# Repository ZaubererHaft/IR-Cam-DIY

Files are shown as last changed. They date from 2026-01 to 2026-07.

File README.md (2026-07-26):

# DIY IR Camera based on the MLX90640 IR sensor array

## Hardware

### Schematic

### Layout

### Chassis

## Software

### Display

### USB

### Sensor

### Flash

## ToDos
* Implement Config file [x]
* Fix saved image [x]
* Activate upscaling when saving image
* Implement battery level with ADC3 [x]
* Implement auto range or definable range
* Fix warnings in user_interface.c
* Replace Error_Handler with a suited dialogue

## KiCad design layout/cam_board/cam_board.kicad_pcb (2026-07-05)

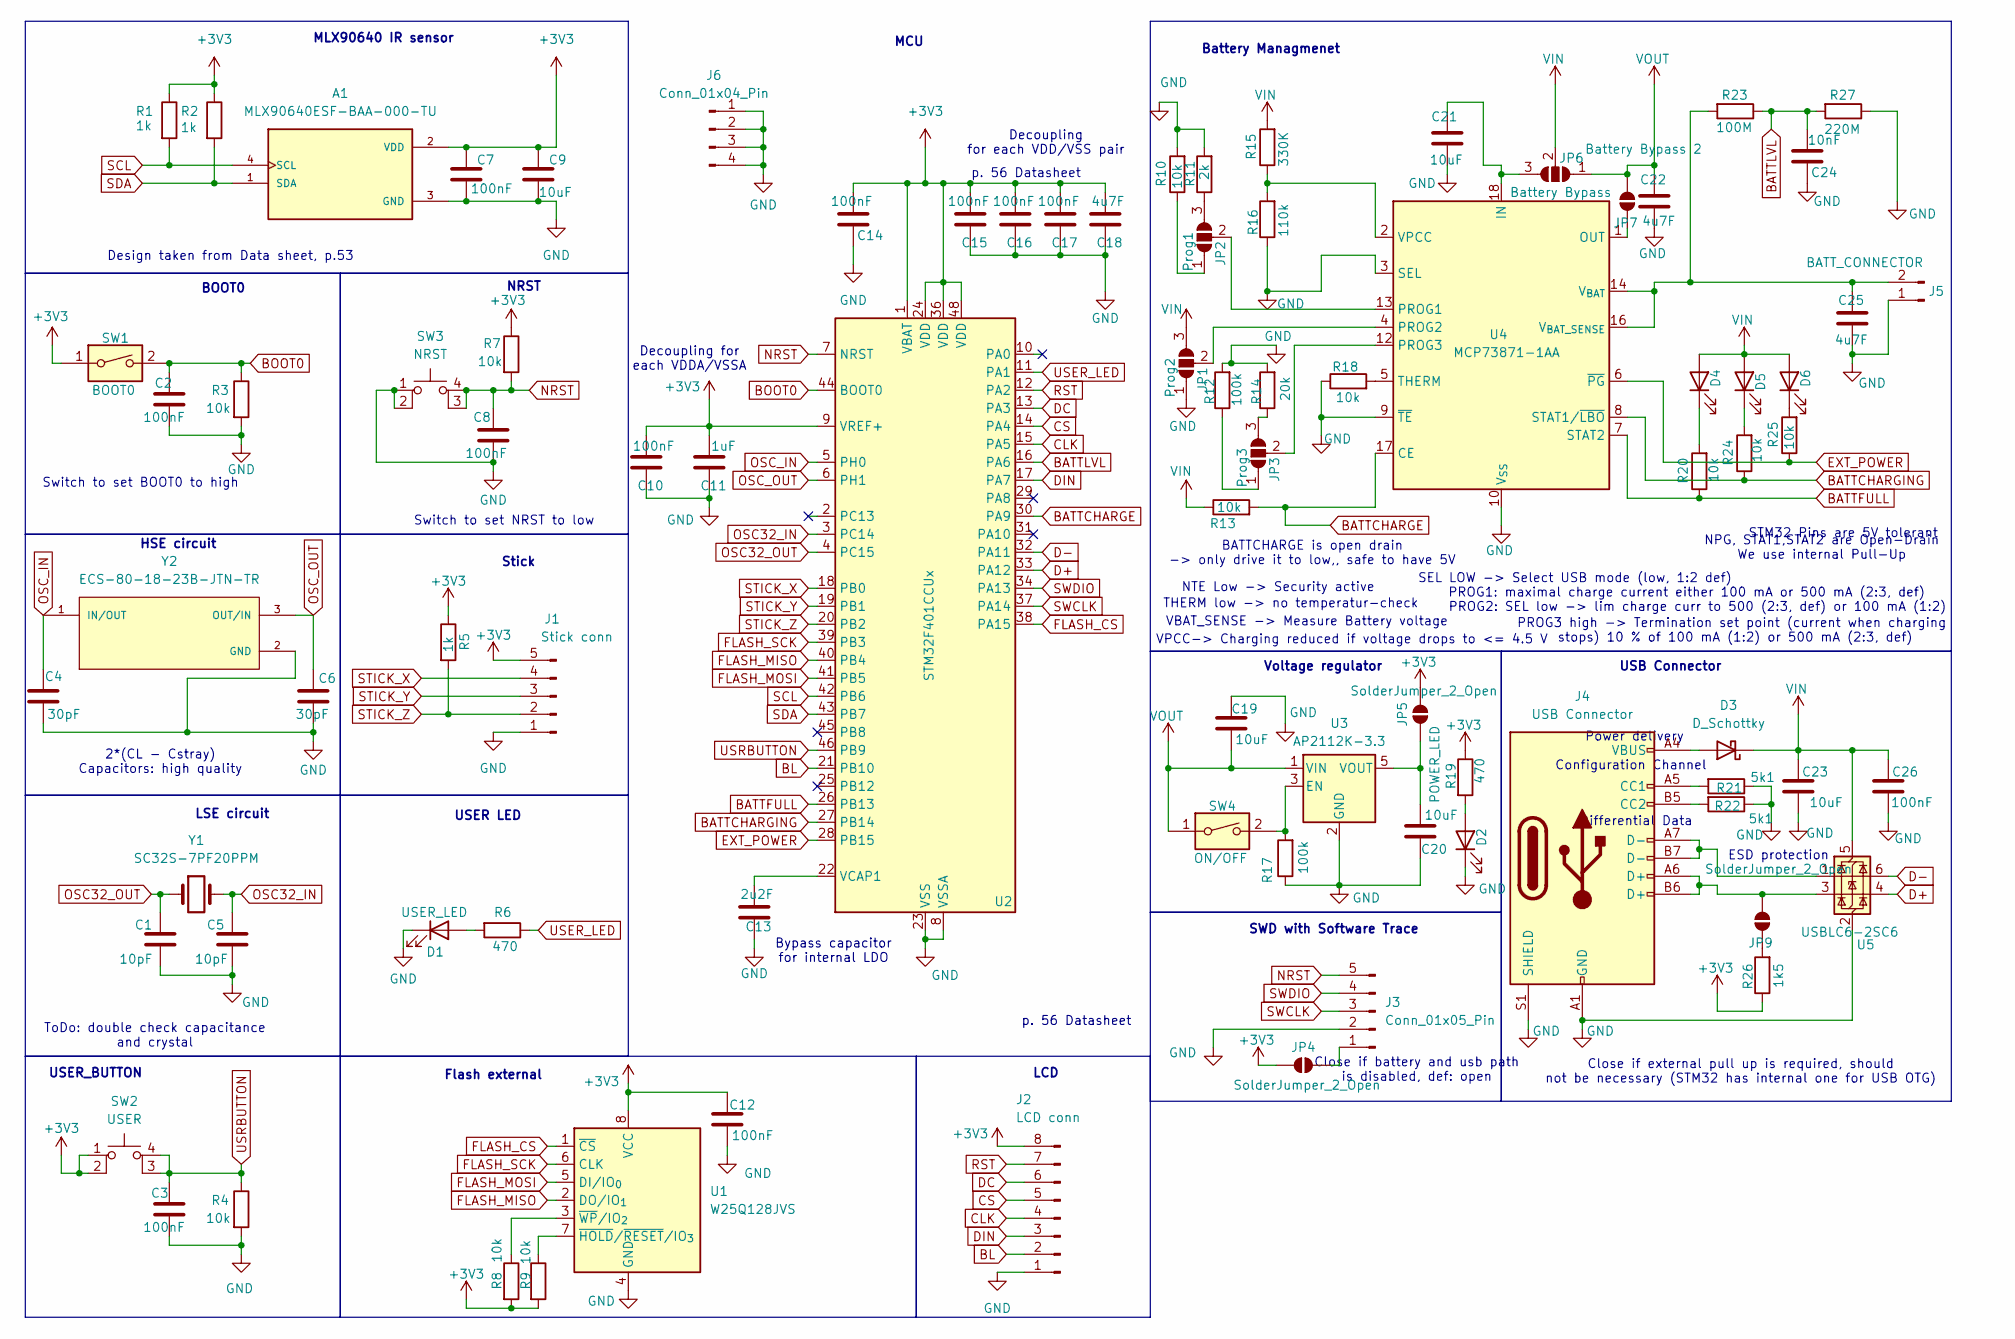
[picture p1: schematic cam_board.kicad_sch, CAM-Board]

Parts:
A1: MLX90640ESF-BAA-000-TU; TO292P930H600-4-MLX; PARTREV 11
C1, C5: 10pF; C_0603_1608Metric_Pad1.08x0.95mm_HandSolder
C2, C3, C7, C8, C10, C12, C14, C15, C16, C17, C26: 100nF; C_0603_1608Metric_Pad1.08x0.95mm_HandSolder
C4, C6: 30pF; C_0603_1608Metric_Pad1.08x0.95mm_HandSolder
C9, C19, C20, C21, C23: 10uF; C_0603_1608Metric_Pad1.08x0.95mm_HandSolder
C11: 1uF; C_0603_1608Metric_Pad1.08x0.95mm_HandSolder
C13: 2u2F; C_0603_1608Metric_Pad1.08x0.95mm_HandSolder
C18, C22, C25: 4u7F; C_0603_1608Metric_Pad1.08x0.95mm_HandSolder
C24: 10nF; C_0603_1608Metric_Pad1.08x0.95mm_HandSolder
D1: USER_LED; LED_0603_1608Metric_Pad1.05x0.95mm_HandSolder
D2, D4, D5, D6: POWER_LED; LED_0603_1608Metric_Pad1.05x0.95mm_HandSolder
D3: D_Schottky; D_0603_1608Metric_Pad1.05x0.95mm_HandSolder
J1: Stick conn; PinHeader_1x05_P2.54mm_Vertical
J2: LCD conn; PinHeader_1x08_P2.54mm_Vertical
J3: Conn_01x05_Pin; PinHeader_1x05_P2.54mm_Vertical
J4: USB Connector; USB_C_Receptacle_HRO_TYPE-C-31-M-12
J5: BATT_CONNECTOR; JST_PH_B2B-PH-K_1x02_P2.00mm_Vertical
J6: Conn_01x04_Pin; PinHeader_1x04_P2.54mm_Vertical
JP1: Prog2; SolderJumper-3_P1.3mm_Open_RoundedPad1.0x1.5mm_NumberLabels
JP2: Prog1; SolderJumper-3_P1.3mm_Open_RoundedPad1.0x1.5mm_NumberLabels
JP3: Prog3; SolderJumper-3_P1.3mm_Open_RoundedPad1.0x1.5mm_NumberLabels
JP4, JP5, JP9: SolderJumper_2_Open; SolderJumper-2_P1.3mm_Open_RoundedPad1.0x1.5mm
JP6: Battery Bypass; SolderJumper-3_P1.3mm_Open_RoundedPad1.0x1.5mm_NumberLabels
JP7: Battery Bypass 2; SolderJumper-2_P1.3mm_Open_RoundedPad1.0x1.5mm
R1, R2, R5: 1k; R_0603_1608Metric_Pad0.98x0.95mm_HandSolder
R3, R4, R7, R8, R9, R10, R13, R18, R20, R24, R25: 10k; R_0603_1608Metric_Pad0.98x0.95mm_HandSolder
R6, R19: 470; R_0603_1608Metric_Pad0.98x0.95mm_HandSolder
R11: 2k; R_0603_1608Metric_Pad0.98x0.95mm_HandSolder
R12, R17: 100k; R_0603_1608Metric_Pad0.98x0.95mm_HandSolder
R14: 20k; R_0603_1608Metric_Pad0.98x0.95mm_HandSolder
R15: 330K; R_0603_1608Metric_Pad0.98x0.95mm_HandSolder
R16: 110k; R_0603_1608Metric_Pad0.98x0.95mm_HandSolder
R21, R22: 5k1; R_0603_1608Metric_Pad0.98x0.95mm_HandSolder
R23: 100M; R_0603_1608Metric_Pad0.98x0.95mm_HandSolder
R26: 1k5; R_0603_1608Metric_Pad0.98x0.95mm_HandSolder
R27: 220M; R_0603_1608Metric_Pad0.98x0.95mm_HandSolder
SW1: BOOT0; SW_DIP_SPSTx01_Slide_9.78x4.72mm_W7.62mm_P2.54mm
SW2: USER; SW_1825910-6-4
SW3: NRST; SW_1825910-6-4
SW4: ON/OFF; SW_DIP_SPSTx01_Slide_9.78x4.72mm_W7.62mm_P2.54mm
U1: W25Q128JVS; SOIC-8_5.3x5.3mm_P1.27mm
U2: STM32F401CCUx; QFN-48-1EP_7x7mm_P0.5mm_EP5.6x5.6mm
U3: AP2112K-3.3; SOT-23-5_HandSoldering
U4: MCP73871-1AA; QFN-20-1EP_4x4mm_P0.5mm_EP2.5x2.5mm_ThermalVias
U5: USBLC6-2SC6; SOT-23-6_Handsoldering
Y1: SC32S-7PF20PPM; XTAL_CTS3-32.768-12.5-20-CT
Y2: ECS-80-18-23B-JTN-TR; XTAL_ECS-80-18-23B-JTN-TR

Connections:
+3V3: A1.2 (VDD), C7.2, C9.2, C10.2, C11.2, C12.2, C14.2, C15.2, C16.2, C17.2, C18.2, J1.5, J2.8, JP4.1 (A), JP5.2 (B), R1.1, R2.1, R5.1, R7.1, R8.2, R9.2, R19.1, R26.1, SW1.1, SW2.1, SW2.2, U1.8 (VCC), U2.1 (VBAT), U2.9 (VREF+), U2.24 (VDD), U2.36 (VDD), U2.48 (VDD)
BATTCHARGE: R13.2, U2.30 (PA9), U4.17 (CE)
BATTCHARGING: R24.1, U2.27 (PB14), U4.8 (STAT1/~LBO)
BATTFULL: R20.1, U2.26 (PB13), U4.7 (STAT2)
BATTLVL: C24.2, R23.1, R27.2, U2.16 (PA6)
BL: J2.2, U2.21 (PB10)
BOOT0: C2.2, R3.1, SW1.2, U2.44 (BOOT0)
CLK: J2.4, U2.15 (PA5)
CS: J2.5, U2.14 (PA4)
D+: U2.33 (PA12), U5.4 (I/O2)
D-: U2.32 (PA11), U5.6 (I/O1)
DC: J2.6, U2.13 (PA3)
DIN: J2.3, U2.17 (PA7)
EXT_POWER: R25.1, U2.28 (PB15), U4.6 (~PG)
FLASH_CS: U1.1 (~CS), U2.38 (PA15)
FLASH_MISO: U1.2 (DO/IO_{1}), U2.40 (PB4)
FLASH_MOSI: U1.5 (DI/IO_{0}), U2.41 (PB5)
FLASH_SCK: U1.6 (CLK), U2.39 (PB3)
GND: A1.3 (GND), C1.1, C2.1, C3.1, C4.1, C5.1, C6.1, C7.1, C8.1, C9.1, C10.1, C11.1, C12.1, C13.1, C14.1, C15.1, C16.1, C17.1, C18.1, C19.2, C20.2, C21.1, C22.1, C23.1, C24.1, C25.1, C26.1, D1.1 (K), D2.1 (K), J1.1, J2.1, J3.2, J4.A1 (GND), J4.A12 (GND), J4.B1 (GND), J4.B12 (GND), J4.S1 (SHIELD), J5.1, J6.1, J6.2, J6.3, J6.4, JP1.1 (A), R3.2, R4.2, R10.2, R11.2, R12.2, R14.2, R16.1, R17.1, R18.1, R21.1, R22.1, R27.1, SW3.1, SW3.2, U1.4 (GND), U2.8 (VSSA), U2.23 (VSS), U2.35 (VSS), U2.47 (VSS), U2.49 (VSS), U3.2 (GND), U4.3 (SEL), U4.9 (~TE), U4.10 (V_{SS}), U4.11 (V_{SS}), U4.21 (V_{SS}), U5.2 (GND), Y2.2 (GND), Y2.4 (GND)
NRST: C8.2, J3.5, R7.2, SW3.3 (K), SW3.4 (A), U2.7 (NRST)
unnamed: D1.2 (A), R6.2
unnamed: D2.2 (A), R19.2
unnamed: D3.2 (A), J4.A4 (VBUS), J4.A9 (VBUS), J4.B4 (VBUS), J4.B9 (VBUS)
unnamed: D4.1 (K), R20.2
unnamed: D5.1 (K), R24.2
unnamed: D6.1 (K), R25.2
unnamed: J3.1, JP4.2 (B)
unnamed: J4.A5 (CC1), R21.2
unnamed: J4.B5 (CC2), R22.2
unnamed: J4.A7 (D-), J4.B7 (D-), U5.1 (I/O1)
unnamed: C25.2, J5.2, R23.2, U4.14 (V_{BAT}), U4.15 (V_{BAT}), U4.16 (V_{BAT_SENSE})
unnamed: JP1.2 (C), U4.4 (PROG2)
unnamed: JP2.1 (A), R10.1
unnamed: JP2.3 (B), R11.1
unnamed: JP2.2 (C), U4.13 (PROG1)
unnamed: JP3.1 (A), R12.1
unnamed: JP3.3 (B), R14.1
unnamed: JP3.2 (C), U4.12 (PROG3)
unnamed: C20.1, JP5.1 (A), U3.5 (VOUT)
unnamed: C21.2, JP6.3 (B), U4.18 (IN), U4.19 (IN)
unnamed: JP7.1 (A), U4.1 (OUT), U4.20 (OUT)
unnamed: JP9.1 (A), R26.2
unnamed: J4.A6 (D+), J4.B6 (D+), JP9.2 (B), U5.3 (I/O2)
unnamed: R9.1, U1.7 (~HOLD/~RESET/IO_{3})
unnamed: R8.1, U1.3 (~WP/IO_{2})
unnamed: C13.2, U2.22 (VCAP1)
unnamed: R17.2, SW4.2, U3.3 (EN)
unnamed: R18.2, U4.5 (THERM)
unnamed: R15.1, R16.2, U4.2 (VPCC)
OSC32_IN: C5.2, U2.3 (PC14), Y1.2
OSC32_OUT: C1.2, U2.4 (PC15), Y1.1
OSC_IN: C4.2, U2.5 (PH0), Y2.1 (IN/OUT)
OSC_OUT: C6.2, U2.6 (PH1), Y2.3 (OUT/IN)
RST: J2.7, U2.12 (PA2)
SCL: A1.4 (SCL), R1.2, U2.42 (PB6)
SDA: A1.1 (SDA), R2.2, U2.43 (PB7)
STICK_X: J1.4, U2.18 (PB0)
STICK_Y: J1.3, U2.19 (PB1)
STICK_Z: J1.2, R5.2, U2.20 (PB2)
SWCLK: J3.3, U2.37 (PA14)
SWDIO: J3.4, U2.34 (PA13)
USER_LED: R6.1, U2.11 (PA1)
USRBUTTON: C3.2, R4.1, SW2.3 (K), SW2.4 (A), U2.46 (PB9)
VIN: C23.2, C26.2, D3.1 (K), D4.2 (A), D5.2 (A), D6.2 (A), JP1.3 (B), JP6.2 (C), R13.1, R15.2, U5.5 (VBUS)
VOUT: C19.1, C22.2, JP6.1 (A), JP7.2 (B), SW4.1, U3.1 (VIN)

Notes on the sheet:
USER LED
NPG, STAT1,STAT2 are Open-Drain We use internal Pull-Up
PROG2: SEL low -> lim charge curr to 500 (2:3, def) or 100 mA (1:2)
Flash external
Voltage regulator
p. 56 Datasheet
SWD with Software Trace
THERM low -> no temperatur-check
NTE Low -> Security active
Stick
Decoupling for each VDDA/VSSA
Switch to set NRST to low
BOOT0
VPCC-> Charging reduced if voltage drops to <= 4.5 V
Battery Managmenet
SEL LOW -> Select USB mode (low, 1:2 def)
Configuration Channel
Power delivery
USB Connector
ESD protection
ToDo: double check capacitance and crystal
Close if battery and usb path is disabled, def: open
PROG1: maximal charge current either 100 mA or 500 mA (2:3, def)
Switch to set BOOT0 to high
Decoupling for each VDD/VSS pair
Design taken from Data sheet, p.53
2*(CL - Cstray) Capacitors: high quality
USER_BUTTON
MLX90640 IR sensor
HSE circuit
LSE circuit
MCU
BATTCHARGE is open drain -> only drive it to low,, safe to have 5V
Differential Data
Close if external pull up is required, should not be necessary (STM32 has internal one for USB OTG)
PROG3 high -> Termination set point (current when charging stops) 10 % of 100 mA (1:2) or 500 mA (2:3, def)
VBAT_SENSE -> Measure Battery voltage
STM32 Pins are 5V tolerant
LCD
Bypass capacitor for internal LDO

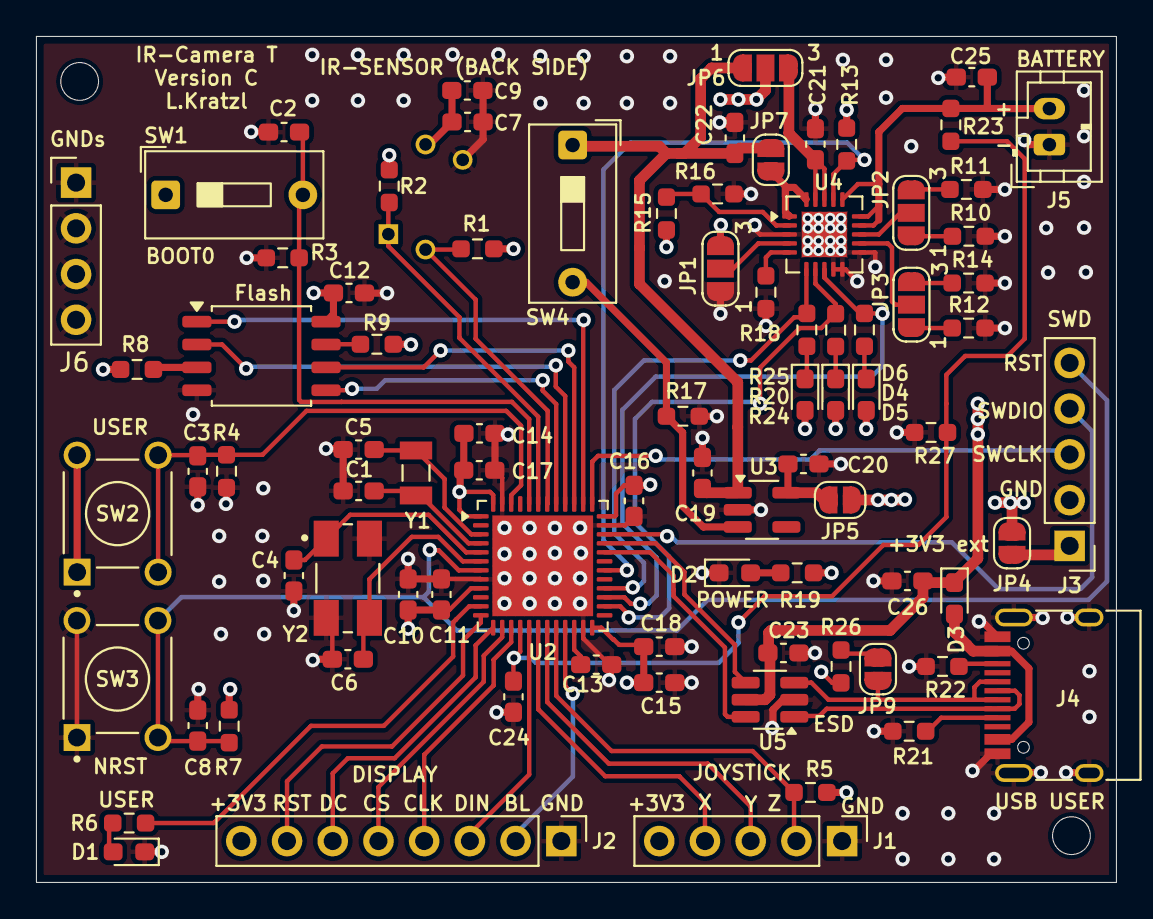
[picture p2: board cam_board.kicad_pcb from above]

Board: 4 copper layers, 60.0 x 47.0 mm, 87 parts (1 on the bottom side), 65 nets.

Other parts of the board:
M1, M2: MountingHole_2.1mm

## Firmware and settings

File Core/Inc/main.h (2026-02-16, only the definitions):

#define USER_LED_Pin GPIO_PIN_1
#define USER_LED_GPIO_Port GPIOA
#define RST_Pin GPIO_PIN_2
#define RST_GPIO_Port GPIOA
#define DC_Pin GPIO_PIN_3
#define DC_GPIO_Port GPIOA
#define CS_Pin GPIO_PIN_4
#define CS_GPIO_Port GPIOA
#define CLK_Pin GPIO_PIN_5
#define CLK_GPIO_Port GPIOA
#define BATTLVL_Pin GPIO_PIN_6
#define BATTLVL_GPIO_Port GPIOA
#define DIN_Pin GPIO_PIN_7
#define DIN_GPIO_Port GPIOA
#define STICK_X_Pin GPIO_PIN_0
#define STICK_X_GPIO_Port GPIOB
#define STICK_Y_Pin GPIO_PIN_1
#define STICK_Y_GPIO_Port GPIOB
#define STICK_Z_Pin GPIO_PIN_2
#define STICK_Z_GPIO_Port GPIOB
#define STICK_Z_EXTI_IRQn EXTI2_IRQn
#define BL_Pin GPIO_PIN_10
#define BL_GPIO_Port GPIOB
#define BATTFULL_Pin GPIO_PIN_13
#define BATTFULL_GPIO_Port GPIOB
#define BATTCHARGING_Pin GPIO_PIN_14
#define BATTCHARGING_GPIO_Port GPIOB
#define EXT_POWER_Pin GPIO_PIN_15
#define EXT_POWER_GPIO_Port GPIOB
#define BATTCHARGE_Pin GPIO_PIN_9
#define BATTCHARGE_GPIO_Port GPIOA
#define FLASH_CS_Pin GPIO_PIN_15
#define FLASH_CS_GPIO_Port GPIOA
#define FLASH_SCK_Pin GPIO_PIN_3
#define FLASH_SCK_GPIO_Port GPIOB
#define FLASH_MISO_Pin GPIO_PIN_4
#define FLASH_MISO_GPIO_Port GPIOB
#define FLASH_MOSI_Pin GPIO_PIN_5
#define FLASH_MOSI_GPIO_Port GPIOB
#define SCL_Pin GPIO_PIN_6
#define SCL_GPIO_Port GPIOB
#define SDA_Pin GPIO_PIN_7
#define SDA_GPIO_Port GPIOB
#define USRBUTTON_Pin GPIO_PIN_9
#define USRBUTTON_GPIO_Port GPIOB

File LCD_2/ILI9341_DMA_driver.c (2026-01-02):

//	MIT License
//
//	Copyright (c) 2017 Matej Artnak
//
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
//
//
//-----------------------------------
//	ILI9341 GFX library for STM32
//-----------------------------------
//
//	Very simple GFX library built upon ILI9342_STM32_Driver library.
//	Adds basic shapes, image and font drawing capabilities to ILI9341
//
//	Library is written for STM32 HAL library and supports STM32CUBEMX. To use the library with Cube software
//	you need to tick the box that generates peripheral initialization code in their own respective .c and .h file




/* Includes ------------------------------------------------------------------*/
#include "ILI9341_DMA_driver.h"
#include "main.h"

/* Global Variables ------------------------------------------------------------------*/
volatile uint16_t LCD_HEIGHT = ILI9341_SCREEN_HEIGHT;
volatile uint16_t LCD_WIDTH = ILI9341_SCREEN_WIDTH;

extern uint8_t SPI2_TX_completed_flag;

/* Initialize SPI */
void ILI9341_SPI_Init(void)
{
	//Peripherials initializations are unnecessary when using code generated by CubeMX

}



void ILI9341_SPI_Send(uint8_t SPI_Data)
{
	SPI2_TX_completed_flag = 0;
	HAL_SPI_Transmit_DMA(HSPI_INSTANCE, &SPI_Data, 1);
	while (SPI2_TX_completed_flag == 0);
}

void ILI9341_Write_Command(uint8_t Command)
{
	HAL_GPIO_WritePin(LCD_CS_PORT, LCD_CS_PIN, GPIO_PIN_RESET);
	HAL_GPIO_WritePin(LCD_DC_PORT, LCD_DC_PIN, GPIO_PIN_RESET);
	ILI9341_SPI_Send(Command);
	HAL_GPIO_WritePin(LCD_CS_PORT, LCD_CS_PIN, GPIO_PIN_SET);
}

void ILI9341_Write_Data(uint8_t Data)
{
	HAL_GPIO_WritePin(LCD_DC_PORT, LCD_DC_PIN, GPIO_PIN_SET);
	HAL_GPIO_WritePin(LCD_CS_PORT, LCD_CS_PIN, GPIO_PIN_RESET);
	ILI9341_SPI_Send(Data);
	HAL_GPIO_WritePin(LCD_CS_PORT, LCD_CS_PIN, GPIO_PIN_SET);
}

void ILI9341_Set_Address(uint16_t X1, uint16_t Y1, uint16_t X2, uint16_t Y2)
{
	ILI9341_Write_Command(0x2A);
	ILI9341_Write_Data(X1 >> 8);
	ILI9341_Write_Data(X1);
	ILI9341_Write_Data(X2 >> 8);
	ILI9341_Write_Data(X2);

	ILI9341_Write_Command(0x2B);
	ILI9341_Write_Data(Y1 >> 8);
	ILI9341_Write_Data(Y1);
	ILI9341_Write_Data(Y2 >> 8);
	ILI9341_Write_Data(Y2);

	ILI9341_Write_Command(0x2C);
}

/*HARDWARE RESET*/
void ILI9341_Reset(void)
{
	HAL_GPIO_WritePin(LCD_RST_PORT, LCD_RST_PIN, GPIO_PIN_RESET);
	HAL_Delay(200);
	HAL_GPIO_WritePin(LCD_CS_PORT, LCD_CS_PIN, GPIO_PIN_RESET);
	HAL_Delay(200);
	HAL_GPIO_WritePin(LCD_RST_PORT, LCD_RST_PIN, GPIO_PIN_SET);
}

/*Set rotation of the screen - changes x0 and y0*/
void ILI9341_Set_Rotation(uint8_t Rotation)
{

	uint8_t screen_rotation = Rotation;

	ILI9341_Write_Command(0x36);
	HAL_Delay(1);

	switch (screen_rotation)
	{
	case SCREEN_VERTICAL_1:
		ILI9341_Write_Data(0x40 | 0x08);
		LCD_WIDTH = 240;
		LCD_HEIGHT = 320;
		break;
	case SCREEN_HORIZONTAL_1:
		ILI9341_Write_Data(0x20 | 0x08);
		LCD_WIDTH = 320;
		LCD_HEIGHT = 240;
		break;
	case SCREEN_VERTICAL_2:
		ILI9341_Write_Data(0x80 | 0x08);
		LCD_WIDTH = 240;
		LCD_HEIGHT = 320;
		break;
	case SCREEN_HORIZONTAL_2:
		ILI9341_Write_Data(0x40 | 0x80 | 0x20 | 0x08);
		LCD_WIDTH = 320;
		LCD_HEIGHT = 240;
		break;
	default:
		//EXIT IF SCREEN ROTATION NOT VALID!
		break;
	}
}

/*Enable LCD display*/
void ILI9341_Enable(void)
{
	HAL_GPIO_WritePin(LCD_RST_PORT, LCD_RST_PIN, GPIO_PIN_SET);
}

/*Initialize LCD display*/
void ILI9341_Init(void)
{

	ILI9341_Enable();
	ILI9341_SPI_Init();
	ILI9341_Reset();

//SOFTWARE RESET
	ILI9341_Write_Command(0x01);
	HAL_Delay(1000);

//POWER CONTROL A
	ILI9341_Write_Command(0xCB);
	ILI9341_Write_Data(0x39);
	ILI9341_Write_Data(0x2C);
	ILI9341_Write_Data(0x00);
	ILI9341_Write_Data(0x34);
	ILI9341_Write_Data(0x02);

//POWER CONTROL B
	ILI9341_Write_Command(0xCF);
	ILI9341_Write_Data(0x00);
	ILI9341_Write_Data(0xC1);
	ILI9341_Write_Data(0x30);

//DRIVER TIMING CONTROL A
	ILI9341_Write_Command(0xE8);
	ILI9341_Write_Data(0x85);
	ILI9341_Write_Data(0x00);
	ILI9341_Write_Data(0x78);

//DRIVER TIMING CONTROL B
	ILI9341_Write_Command(0xEA);
	ILI9341_Write_Data(0x00);
	ILI9341_Write_Data(0x00);

//POWER ON SEQUENCE CONTROL
	ILI9341_Write_Command(0xED);
	ILI9341_Write_Data(0x64);
	ILI9341_Write_Data(0x03);
	ILI9341_Write_Data(0x12);
	ILI9341_Write_Data(0x81);

//PUMP RATIO CONTROL
	ILI9341_Write_Command(0xF7);
	ILI9341_Write_Data(0x20);

//POWER CONTROL,VRH[5:0]
	ILI9341_Write_Command(0xC0);
	ILI9341_Write_Data(0x23);

//POWER CONTROL,SAP[2:0];BT[3:0]
	ILI9341_Write_Command(0xC1);
	ILI9341_Write_Data(0x10);

//VCM CONTROL
	ILI9341_Write_Command(0xC5);
	ILI9341_Write_Data(0x3E);
	ILI9341_Write_Data(0x28);

//VCM CONTROL 2
	ILI9341_Write_Command(0xC7);
	ILI9341_Write_Data(0x86);

//MEMORY ACCESS CONTROL
	ILI9341_Write_Command(0x36);
	ILI9341_Write_Data(0x48);

//PIXEL FORMAT
	ILI9341_Write_Command(0x3A);
	ILI9341_Write_Data(0x55);

//FRAME RATIO CONTROL, STANDARD RGB COLOR
	ILI9341_Write_Command(0xB1);
	ILI9341_Write_Data(0x00);
	ILI9341_Write_Data(0x18);

//DISPLAY FUNCTION CONTROL
	ILI9341_Write_Command(0xB6);
	ILI9341_Write_Data(0x08);
	ILI9341_Write_Data(0x82);
	ILI9341_Write_Data(0x27);

//3GAMMA FUNCTION DISABLE
	ILI9341_Write_Command(0xF2);
	ILI9341_Write_Data(0x00);

//GAMMA CURVE SELECTED
	ILI9341_Write_Command(0x26);
	ILI9341_Write_Data(0x01);

//POSITIVE GAMMA CORRECTION
	ILI9341_Write_Command(0xE0);
	ILI9341_Write_Data(0x0F);
	ILI9341_Write_Data(0x31);
	ILI9341_Write_Data(0x2B);
	ILI9341_Write_Data(0x0C);
	ILI9341_Write_Data(0x0E);
	ILI9341_Write_Data(0x08);
	ILI9341_Write_Data(0x4E);
	ILI9341_Write_Data(0xF1);
	ILI9341_Write_Data(0x37);
	ILI9341_Write_Data(0x07);
	ILI9341_Write_Data(0x10);
	ILI9341_Write_Data(0x03);
	ILI9341_Write_Data(0x0E);
	ILI9341_Write_Data(0x09);
	ILI9341_Write_Data(0x00);

//NEGATIVE GAMMA CORRECTION
	ILI9341_Write_Command(0xE1);
	ILI9341_Write_Data(0x00);
	ILI9341_Write_Data(0x0E);
	ILI9341_Write_Data(0x14);
	ILI9341_Write_Data(0x03);
	ILI9341_Write_Data(0x11);
	ILI9341_Write_Data(0x07);
	ILI9341_Write_Data(0x31);
	ILI9341_Write_Data(0xC1);
	ILI9341_Write_Data(0x48);
	ILI9341_Write_Data(0x08);
	ILI9341_Write_Data(0x0F);
	ILI9341_Write_Data(0x0C);
	ILI9341_Write_Data(0x31);
	ILI9341_Write_Data(0x36);
	ILI9341_Write_Data(0x0F);

//EXIT SLEEP
	ILI9341_Write_Command(0x11);
	HAL_Delay(120);

//TURN ON DISPLAY
	ILI9341_Write_Command(0x29);

//STARTING ROTATION
	ILI9341_Set_Rotation(SCREEN_VERTICAL_1);
}

void ILI9341_Draw_Colour(uint16_t Colour)
{
//SENDS COLOUR
	unsigned char TempBuffer[2] =
	{ Colour >> 8, Colour };
	HAL_GPIO_WritePin(LCD_DC_PORT, LCD_DC_PIN, GPIO_PIN_SET);
	HAL_GPIO_WritePin(LCD_CS_PORT, LCD_CS_PIN, GPIO_PIN_RESET);

	SPI2_TX_completed_flag = 0;
	HAL_SPI_Transmit_DMA(HSPI_INSTANCE, TempBuffer, 2);
	while (SPI2_TX_completed_flag == 0)

	HAL_GPIO_WritePin(LCD_CS_PORT, LCD_CS_PIN, GPIO_PIN_SET);
}
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

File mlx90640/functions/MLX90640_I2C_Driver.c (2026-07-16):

/**
 * @copyright (C) 2017 Melexis N.V.
 *
 * Licensed under the Apache License, Version 2.0 (the "License");
 * you may not use this file except in compliance with the License.
 * You may obtain a copy of the License at
 *
 *     http://www.apache.org/licenses/LICENSE-2.0
 *
 * Unless required by applicable law or agreed to in writing, software
 * distributed under the License is distributed on an "AS IS" BASIS,
 * WITHOUT WARRANTIES OR CONDITIONS OF ANY KIND, either express or implied.
 * See the License for the specific language governing permissions and
 * limitations under the License.
 *
 */
#include <stdio.h>
#include "main.h"
#include "MLX90640_I2C_Driver.h"

extern I2C_HandleTypeDef hi2c1;


void MLX90640_I2CInit() {
    //init already done in main.c
}

int MLX90640_I2CReadAsync(uint8_t slaveAddr, uint16_t startAddress, uint16_t nMemAddressRead, uint16_t *data) {
    uint16_t sizeInBytes = nMemAddressRead * 2;

    if (HAL_I2C_Mem_Read_DMA(&hi2c1, (slaveAddr << 1), startAddress, I2C_MEMADD_SIZE_16BIT, (uint8_t*)data, sizeInBytes) != HAL_OK) {
        return -1;
    }

    return 0;
}


int MLX90640_I2CRead(uint8_t slaveAddr, uint16_t startAddress, uint16_t nMemAddressRead, uint16_t *data) {
    uint8_t *bp = (uint8_t *) data;

    int ack = 0;

    ack = HAL_I2C_Mem_Read(&hi2c1, (slaveAddr << 1), startAddress, I2C_MEMADD_SIZE_16BIT, bp, nMemAddressRead * 2, 500);

    if (ack != HAL_OK) {
        return -1;
    }

    uint16_t *p = (uint16_t *)bp;

    for (uint32_t i = 0; i < nMemAddressRead; i++) {
        p[i] = __REV16(p[i]);
    }

    return 0;
}

int MLX90640_I2CWrite(uint8_t slaveAddr, uint16_t writeAddress, uint16_t data) {
    uint8_t sa;
    int ack = 0;
    uint8_t cmd[2];
    static uint16_t dataCheck;

    sa = (slaveAddr << 1);

    cmd[0] = data >> 8;
    cmd[1] = data & 0x00FF;

    ack = HAL_I2C_Mem_Write(&hi2c1, sa, writeAddress, I2C_MEMADD_SIZE_16BIT, cmd, sizeof(cmd), 500);

    if (ack != HAL_OK) {
        return -1;
    }

    MLX90640_I2CRead(slaveAddr, writeAddress, 1, &dataCheck);

    if (dataCheck != data) {
        return -2;
    }

    return 0;
}

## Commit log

2026-01-01 First prototype
2026-01-02 add heatmap.c
2026-01-03 Several optimizations and button to switch between record and no record
2026-01-03 Add heatmaps
2026-01-03 Heatmap is now dynamic
2026-01-05 Reduce refresh rate and read all sub-pages in the upscaling case
2026-01-08 Further optimizations (getting close to 15 Hz)
2026-01-08 Better heat map
2026-01-11 First DMA attempt
2026-01-11 Fix missing LSB correction
    [MLX90640_API.c]
2026-01-11 Fix missing swap of pages
    [MLX90640_API.c]
2026-01-17 Prototype of menu
2026-01-18 Now use I2C3 instead of I2C2 to use debug trace
2026-01-18 Update layout and schematic
    [cam_board.kicad_sch]
2026-01-20 First full schematic
    [cam_board.kicad_pcb, cam_board.kicad_sch]
2026-02-08 Fix menu, add missing pull-up
    [cam_board.kicad_pcb, cam_board.kicad_sch]
2026-02-13 Prepare USB and fix missing GND line in layout
    [cam_board.kicad_pcb, cam_board.kicad_sch]
2026-02-14 Update board and layout
    [cam_board.kicad_pcb, cam_board.kicad_sch]
2026-02-14 CAM is now using I2C1, add SPI for flash
2026-02-14 Prepare SPI flash
2026-02-16 add to main loop, update layout and schematic
    [cam_board.kicad_pcb, cam_board.kicad_sch]
2026-02-21 Clean up driver
2026-03-01 Update layout
    [cam_board.kicad_pcb]
2026-05-22 Changed foot print to 0603 for allk capacitors Changed footprints for connectors to 2.54 mm Fixed footprint of 32 MHz crystal / Y1 Change slider footprint from SMD to THT Remove USB pull up 1k5 Intro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
    [cam_board.kicad_pcb, cam_board.kicad_sch]
2026-06-04 Update / version B
    [cam_board.kicad_pcb, cam_board.kicad_sch]
2026-06-13 Add optional USB pullup, add more LEDs
    [cam_board.kicad_pcb, cam_board.kicad_sch]
2026-07-01 Re-Mount FS
2026-07-01 no battery or stand by
2026-07-01 Update Layout, add Pullup to BATT Pins
    [cam_board.kicad_pcb, cam_board.kicad_sch]
2026-07-01 Update to new driver
2026-07-05 clean up
    [cam_board.kicad_pcb, cam_board.kicad_sch]
2026-07-12 Enable sensor again
2026-07-16 Try to fix image save
    [MLX90640.c, MLX90640_API.c, MLX90640_API.h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]
2026-07-24 Try to fix issue with saving image
    [MLX90640.c, application.c, user_interface.c]
2026-07-25 Fix issue with saving image
    [MLX90640.c, application.c, user_interface.c]
2026-07-26 Prepare battery lvl display
    [cam_board.kicad_sch]
2026-07-26 display battery lvl
2026-08-08 Implement heatmap save and prepare save others
2026-08-09 Fix invalid index when saving new heatmap
    [user_interface.c]
2026-10-24 Battery animation
2026-10-25 Enable USB connection, add printf with float

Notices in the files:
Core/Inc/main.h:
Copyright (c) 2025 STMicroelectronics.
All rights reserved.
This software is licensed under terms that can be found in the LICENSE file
